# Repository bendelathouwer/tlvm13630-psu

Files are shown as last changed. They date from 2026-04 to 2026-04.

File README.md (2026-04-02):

# circuit explenation 



----------------------------------------------------------------------------------------------------------------------------------------



Now the input circuitry and output circuitry,   the input and output capasitors, the datasheet demands ceramic capasitors with a dielectricum of X7R or better.
Why ceramic capacitors you may ask? because there ESR(equivalent series resitance) is low. which in turn means  lower ripel , control loop is stabel, better transient response and the losses are lower.



For the output circuitry we especialy want that to be suuper stable , why you may ask? Let me show you.



As you can see from this block diagram of the chip  the feedback circuitry is connected (via resistors) to the output. So as you can guess and see any oscilation will upset the comperator which in turn will pass and upset the control circuitry

----------------------------------------------------------------------------------------------------------------------------------


Now we will explain the controll pins a bit.
The first pin we encounter is the Enable pin, which we can use in one of three ways/
The first way is to just tie it to the input voltage , when we do this the convertor will start working whenever a input voltage is present.
The next posibility is to connect an external signal to the enable pin , this can be a microcontroller for example or this can be the power good signal of a upstream convertor.
This is done for when powersequencing is needed , an example of power sequencing can be seen below.



The next and last posebility is to add a voltage devider so we enable the UVLO(Under Voltage Lock Out). This will disable the convertor until a certain voltage is reached or disable the convertor if a voltage dips below a treshold.
This is handy when we are using batterys for example 

The next pin will be the Rt pin ,this pin sets the internal oscilator via a resistor. We need to be careful to choose this resistor. The higher the frequency the more emc and efficency  will become a problem BUT the components can be smaller.
The lower the frequency the lower emc will be and the efficency will be higher BUT the components will be bigger 

The next pin is the VCC pin which comes from the external regulator. Now the datasheet mentions multiple times that there shoudn't be any load connected to the VCC pin BUT in the application schematic in the datasheet it show a load (albeit a pull up).
The EVM schematic shows no load even no pullup connected, so for me it is a mistery if you should or should not connect a load to it.

Next pin is the power good pin , this pin is an open drain pin. This pin will indicate if the convertor works as intended or not.
Also this pin can connect to the enable pin of a downstream converter. So to enable power sequencing as mentiond above.

---------------------------------------------------------------------------------------------------------------------------------------



So the final pin is the feedback pin with it's resistor diverder , this voltage divider will set the input voltage at the input of the controll circuit comperator.
The lower resistor is recomended at 10K and the upper can be a calculated value BUT be awere resistors larger than 1M can introduce noise which in turn will upset the controll circuitry.
Also the feedback trace needs to be short and and bee kept away to again reduce noise.

---------------------------------------------------------------------------------------------------------------------------------------

 # schematic details  
 
As you can see in the overview of the schematic I have a couple of DNP components, I think we all have been there we have our boards in our hands but then we realise some feature of the chip isn't brought out.
So after our little cry we have to spend extra money and time on a new board. So with the DNP parts we have already have a footprint there and so we can easly adapt and continue with a smile.
You will also notice I like to work with collors and net names , the reason behind that is realy simple. So I can see in a blink of an eye what net I am dealing with. This both in the layout side and schematic capture side of things.You will also notice formulas, tables and annotations. This is done so that I don't need to scroll trough the data sheet or have it open on the desktop. We all know engineers have limited desktop space.



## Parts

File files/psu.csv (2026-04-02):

Reference | Qty | Value | Mouser MPN | Mouser price/pcs | Digikey MPN | Digikey price/pcs | LCSC MPN | LCSC price/pcs
C1,C2 | 2 | 4.7u | 581-KGM21AR71E475KU | 0,59 € | 478-KGM21AR71E475KUCT-ND | 0,44 € | 0,44000 € | 0.0137 €
C3 | 1 | 1u | 963-E063SB7222KFCA1J | 0,10 € | 587-MCAST063SB7222KFCA1JTR-ND | 0,01125 € | / | 0 €
C4,C5 | 2 | 4.7u | 963-MLASJ168BB7475KT | 0,32 € | 87-MSASJ168BB7475MTNA01CT-ND | 0,31 € | C22399629 | 0.27 €
R1 | 1 | 10K | 667-ERA-1AEB103C | 0,10 € | P10KBXCT-ND | 0,10 € | C490808 | 0.124 €
R2 | 1 | 22K | 754-RG0603P-223-D | 0,15 € | 408-RG0603P-223-D-T10CT-ND | 0,15 € | C20135502 | 0,16 €
R3 | 1 | 34K | 603-RC0201FR-0734KL | 0,09 € | YAG2614CT-ND | 0,09 € | C273307 | € 0.0009
R7 | 1 | 0 | 71-RCA02010000ZSEDSR | 0,09 € | 541-RCA02010000ZSEDSRCT-ND | 0,09 € | C106228 | 0,0016 €
U1 | 1 |  | 595-TLVM13630RDHR | 3,58 € | 296-TLVM13630RDHRCT-ND | 3,36 € | C5219304 | 4.91 €

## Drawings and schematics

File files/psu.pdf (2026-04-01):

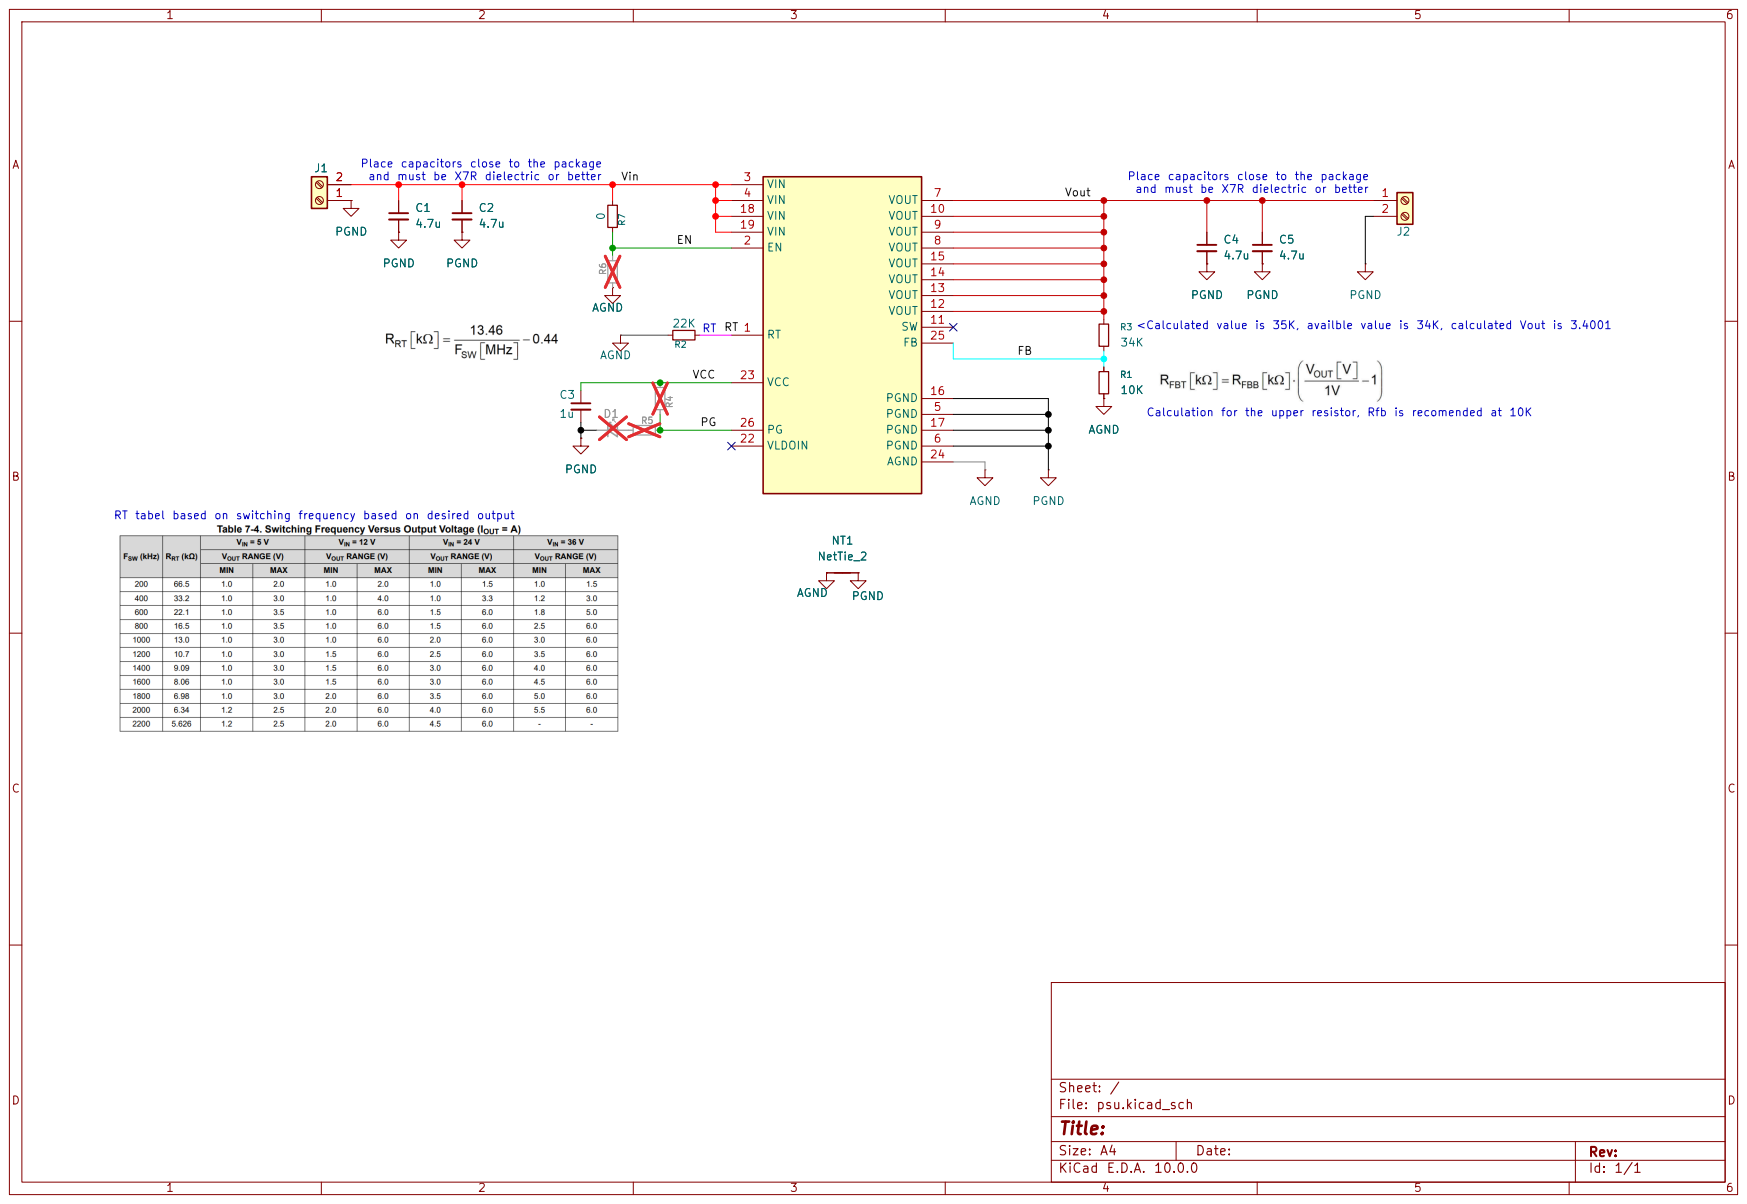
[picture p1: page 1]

Place capacitors close to the package

RT RT tabel based on switching frequency based on desired output

Size: A4 | Rev:
KiCad E.D.A. 10.0.0 | Id: 1/1

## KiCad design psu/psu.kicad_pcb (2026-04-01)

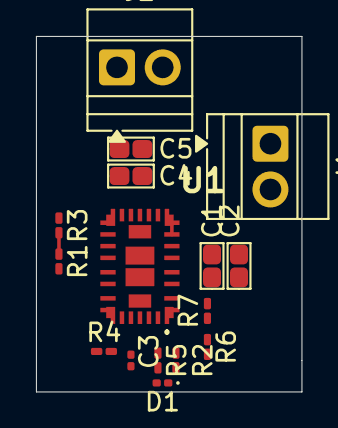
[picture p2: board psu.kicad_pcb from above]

Board: 2 copper layers, 14.8 x 19.8 mm, 16 parts (0 on the bottom side), 10 nets.

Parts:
C1, C2, C4, C5: 4.7u; 0603
C3: 1u; C_0201_0603Metric
D1: LED_Small; LED_0201_0603Metric
J1, J2: Screw_Terminal_01x02; TerminalBlock_Xinya_XY308-2.54-2P_1x02_P2.54mm_Horizontal
R1: 10K; R_0201_0603Metric_Pad0.64x0.40mm_HandSolder
R2: 22K; R_0201_0603Metric_Pad0.64x0.40mm_HandSolder
R3: 34K; R_0201_0603Metric_Pad0.64x0.40mm_HandSolder
R4, R5, R6: R_0201_0603Metric_Pad0.64x0.40mm_HandSolder
R7: 0; R_0201_0603Metric_Pad0.64x0.40mm_HandSolder
U1: TLVM13630

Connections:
/EN: R6.1, R7.1, U1.2 (EN)
/FB: R1.1, R3.2, U1.25 (FB)
/PG: R4.1, R5.1, U1.26 (PG)
/RT: R2.2, U1.1 (RT)
/VCC: C3.1, R4.2, U1.23 (VCC)
/Vin: C1.1, C2.1, J1.2, R7.2, U1.3 (VIN), U1.4 (VIN), U1.18 (VIN), U1.19 (VIN)
/Vout: C4.1, C5.1, J2.1, R3.1, U1.7 (VOUT), U1.8 (VOUT), U1.9 (VOUT), U1.10 (VOUT), U1.12 (VOUT), U1.13 (VOUT), U1.14 (VOUT), U1.15 (VOUT)
AGND: R1.2, R2.1, R6.2, U1.24 (AGND)
unnamed: D1.2 (A), R5.2
PGND: C1.2, C2.2, C3.2, C4.2, C5.2, D1.1 (K), J1.1, J2.2, U1.5 (PGND), U1.6 (PGND), U1.16 (PGND), U1.17 (PGND)

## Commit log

2026-04-01 started
    started working on the psu project
    [psu.kicad_pcb, psu.kicad_sch]
2026-04-01 semi finished the schematic , next up anotation and PCB layout
    [documentation.kicad_sch, psu.kicad_sch]
2026-04-01 added bom and finished the schematic , board will be a pita
    [psu.csv, psu.kicad_pcb, psu.kicad_sch]
2026-04-01 made the pcb , It's a bit trash but still need to make a q&a document
    [psu.csv, psu.kicad_pcb, psu.kicad_sch]
2026-04-01 finished
    finished the schematic , bom and rough pcb outline
    [documentation.kicad_sch, positions.csv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]
2026-04-02 cleaned up the repo
    [psu-B_Cu.gbr, psu-B_Mask.gbr, psu-B_Paste.gbr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]
2026-04-02 Update q&a.md with input circuitry information
    Added details about input circuitry and capacitor specifications.
2026-04-02 Fix grammar and spelling in Q&A about capacitors
    Corrected grammar and spelling errors in the explanation of input capacitors and their benefits.
2026-04-02 Fix formatting of schematic details header
2026-04-02 Update README with feedback pin details
    Added information about the feedback pin in the README.
2026-04-02 Enhance README with DNP components explanation
    Added explanation about DNP components in schematic details.
2026-04-02 Fix typos in README schematic details section
    Corrected typos and improved clarity in the schematic details section.
2026-04-02 Adjust positions in psu.kicad_sch and add backup
    Shifted coordinates for multiple schematic elements (text, image, power symbols, net-tie properties) to refine layout in psu.kicad_sch. Also added a backup archive psu/psu-backups/psu-2026-04-02_2009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
    [psu.kicad_sch]
2026-04-02 Normalize BOM CSV; add backups and history gitignore
    Convert files/psu.csv from quoted comma-separated format to semicolon-separated and clean up price/field formatting for easier parsing. Add psu/.history/.gitignore to ignore fp-info-cache, *-backups 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
    [psu.csv]
